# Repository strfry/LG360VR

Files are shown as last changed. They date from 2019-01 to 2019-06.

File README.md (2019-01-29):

# Summary

This about making the LG 360 VR Goggles usable with a normal DisplayPort outlet.

The LG360VR uses the "DisplayPort over USB-C" standard.
Our assumption is, that with little hardware effort, we can send a DisplayPort signal into it.

# Current State of things

- A passive PCB Adapter has been manufactured, though it doesn't work
- ~~Currently in the process of analyzing USB-PD communication, to figure out if this is the problem~~
  - Resolution: USB-PD Handshake is definitely necessary to get a display connection
- Now designing a new PCB with STM32F072 for PD Handshake and DisplayPort Redriver IC

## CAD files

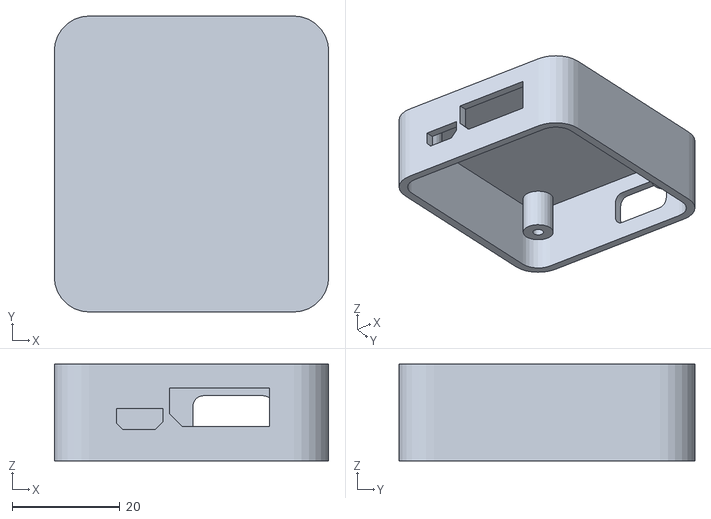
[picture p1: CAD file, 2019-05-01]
case/upper_case.stl
51.0 x 55.0 x 18.0

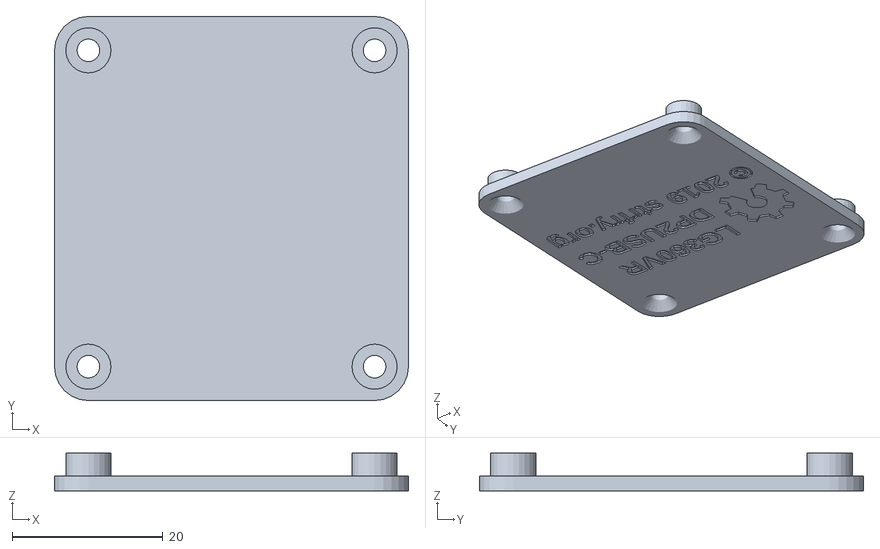
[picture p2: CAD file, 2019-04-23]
case/lower_lid_with_logo.stl
47.0 x 51.0 x 5.00

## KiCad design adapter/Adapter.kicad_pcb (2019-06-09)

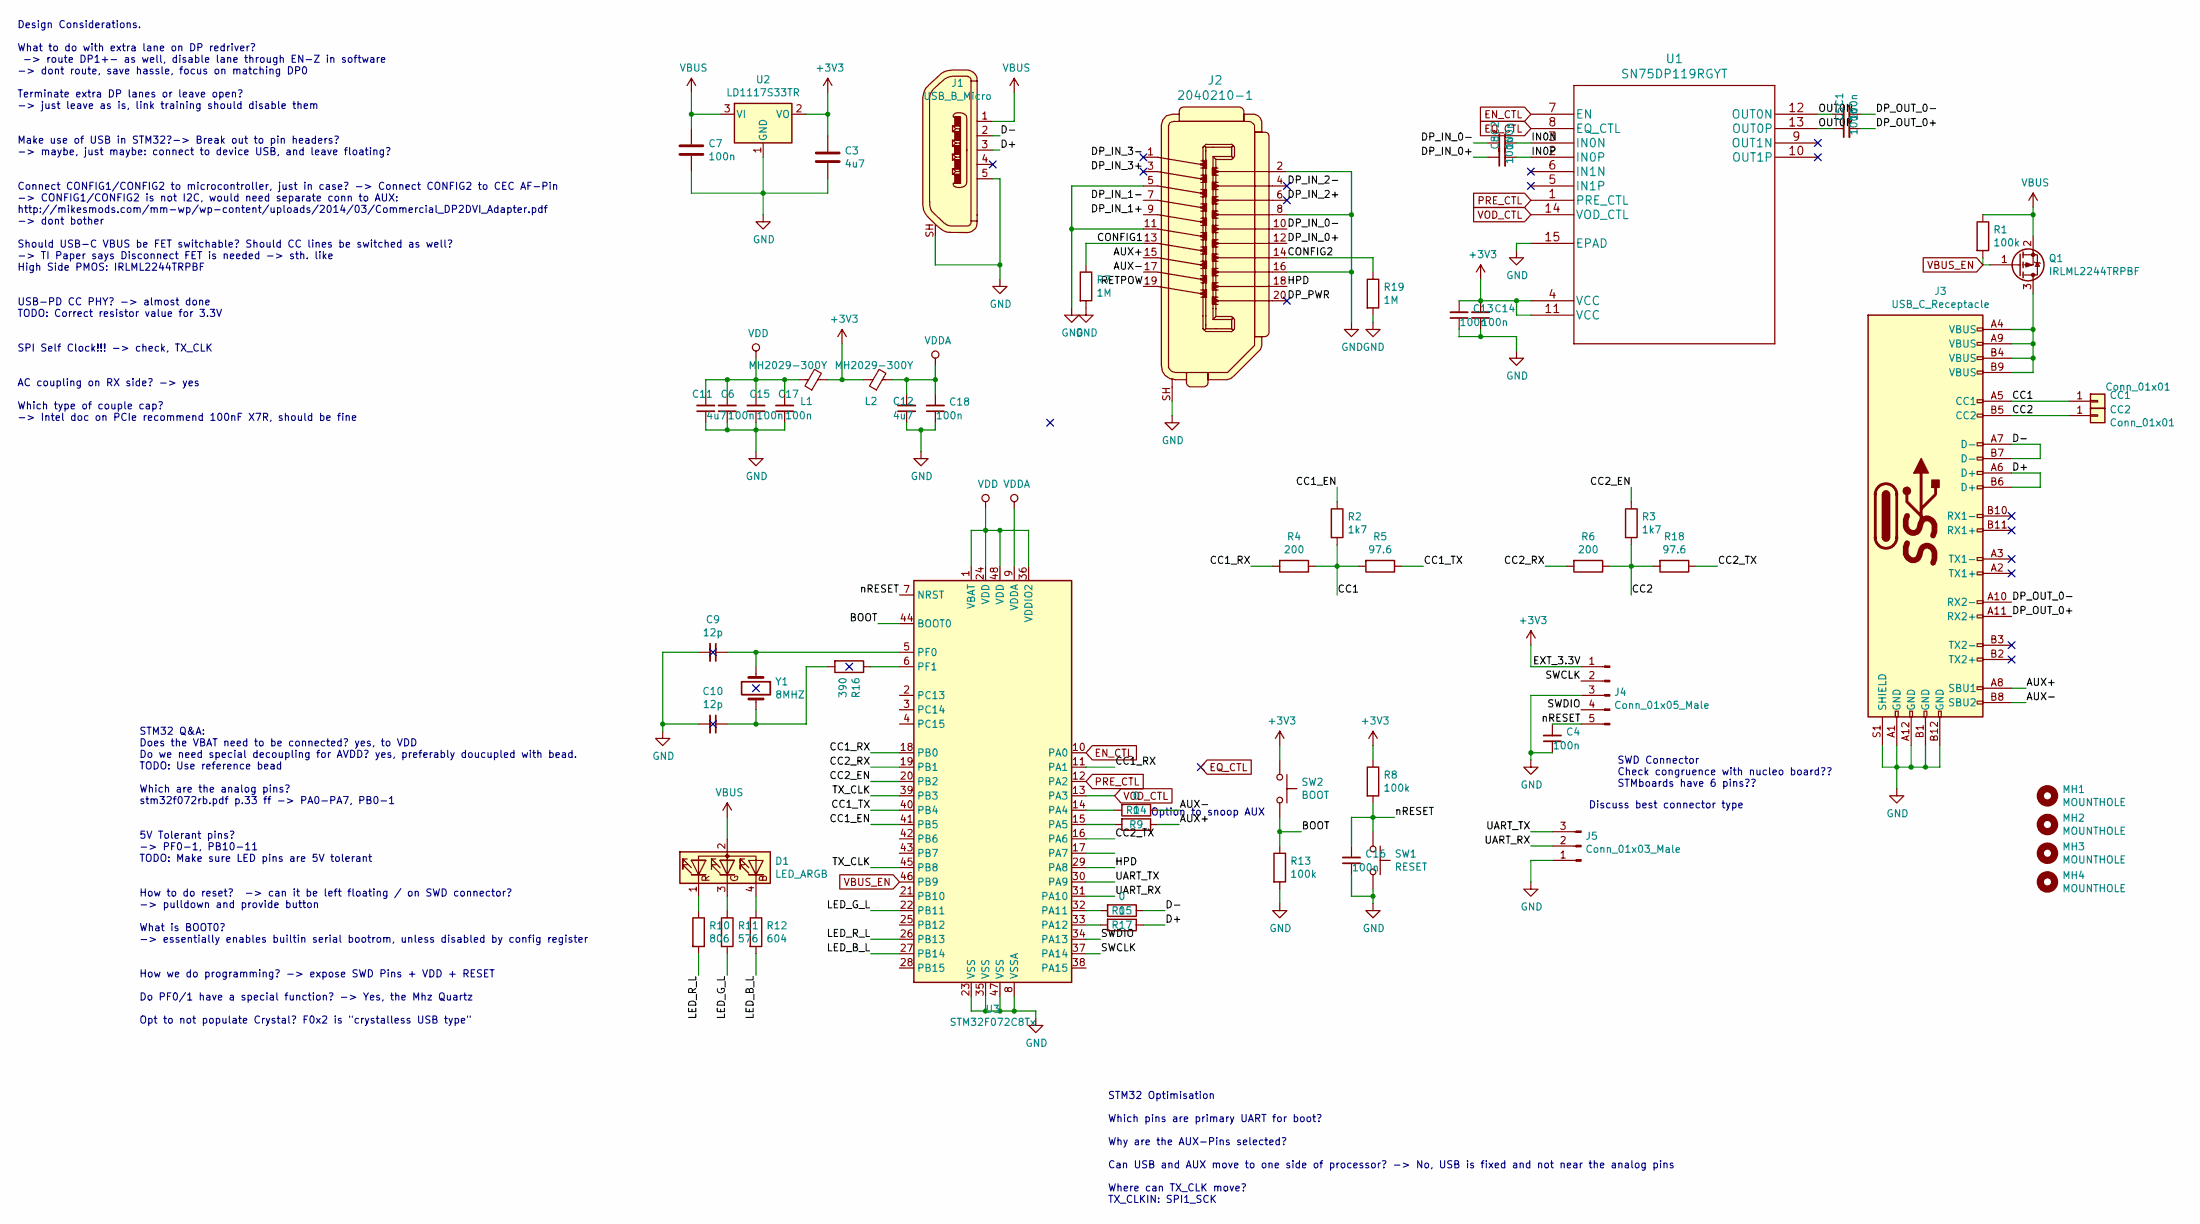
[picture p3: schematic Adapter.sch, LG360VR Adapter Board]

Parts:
C1, C2, C5, C8: 100n; C_0402_1005Metric
C3, C11, C12: 4u7; C_0603_1608Metric_Pad1.05x0.95mm_HandSolder
C4, C6, C7, C13, C14, C15, C16, C17, C18: 100n; C_0603_1608Metric_Pad1.05x0.95mm_HandSolder
C9, C10: 12p; C_0603_1608Metric_Pad1.05x0.95mm_HandSolder
CC1, CC2: Conn_01x01; TestPoint_Pad_D1.0mm
D1: LED_ARGB; LED_Cree-PLCC4_3.2x2.8mm_CCW
J1: USB_B_Micro; CONN-10118194-0001LF-FCI
J2: 2040210-1; DP1RD20JQ1R400
J3: USB_C_Receptacle; USB_C_Receptacle_Amphenol_12401610E4-2A
J4: Conn_01x05_Male; PinHeader_1x05_P2.54mm_Horizontal
J5: Conn_01x03_Male; PinHeader_1x03_P2.54mm_Horizontal
L1, L2: MH2029-300Y; L_0805_2012Metric_Pad1.15x1.40mm_HandSolder
MH1, MH2, MH3, MH4: MOUNTHOLE; MountingHole_2.5mm
Q1: IRLML2244TRPBF; SOT-23
R1, R8, R13: 100k; R_0603_1608Metric_Pad1.05x0.95mm_HandSolder
R2, R3: 1k7; R_0603_1608Metric_Pad1.05x0.95mm_HandSolder
R4, R6: 200; R_0603_1608Metric_Pad1.05x0.95mm_HandSolder
R5, R18: 97.6; R_0603_1608Metric_Pad1.05x0.95mm_HandSolder
R7, R19: 1M; R_0603_1608Metric_Pad1.05x0.95mm_HandSolder
R9, R14, R15, R17: 0; R_0603_1608Metric_Pad1.05x0.95mm_HandSolder
R10: 806; R_0603_1608Metric_Pad1.05x0.95mm_HandSolder
R11: 576; R_0603_1608Metric_Pad1.05x0.95mm_HandSolder
R12: 604; R_0603_1608Metric_Pad1.05x0.95mm_HandSolder
R16: 390; R_0603_1608Metric_Pad1.05x0.95mm_HandSolder
SW1: RESET; EVQPLMA15
SW2: BOOT; EVQPLMA15
U1: SN75DP119RGYT
U2: LD1117S33TR; SOT-223-3_TabPin2
U3: STM32F072C8Tx; LQFP-48_7x7mm_P0.5mm
Y1: 8MHZ; Crystal_SMD_TXC_7A-2Pin_5x3.2mm

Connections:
+3V3: C3.1, C13.2, C14.2, J4.1, L1.2, L2.1, R8.1, SW2.1, U1.4 (VCC), U1.11 (VCC), U2.2 (VO)
/AUX+: J2.15, J3.A8 (SBU1), R9.1
/AUX-: J2.17, J3.B8 (SBU2), R14.1
/BOOT: R13.1, SW2.2, U3.44 (BOOT0)
/CC1: CC1.1, J3.A5 (CC1), R2.2, R4.1, R5.2
/CC1_EN: R2.1, U3.41 (PB5)
/CC1_RX: R4.2, U3.11 (PA1), U3.18 (PB0)
/CC1_TX: R5.1, U3.40 (PB4)
/CC2: CC2.1, J3.B5 (CC2), R3.2, R6.1, R18.2
/CC2_EN: R3.1, U3.20 (PB2)
/CC2_RX: R6.2, U3.19 (PB1)
/CC2_TX: R18.1, U3.16 (PA6)
/CONFIG1: J2.13, R7.1
/CONFIG2: J2.14, R19.1
/D+: J1.3, J3.A6 (D+), J3.B6 (D+), R17.1
/D-: J1.2, J3.A7 (D-), J3.B7 (D-), R15.1
/DP_IN_0+: C8.1, J2.12
/DP_IN_0-: C2.1, J2.10
/DP_IN_1+: J2.9
/DP_IN_1-: J2.7
/DP_IN_2+: J2.6
/DP_IN_2-: J2.4
/DP_IN_3+: J2.3
/DP_IN_3-: J2.1
/DP_OUT_0+: C5.2, J3.A11 (RX2+)
/DP_OUT_0-: C1.2, J3.A10 (RX2-)
/DP_PWR: J2.20
/HPD: J2.18, U3.29 (PA8)
/IN0N: C2.2, U1.3 (IN0N)
/IN0P: C8.2, U1.2 (IN0P)
/LED_B_L: R12.2, U3.27 (PB14)
/LED_G_L: R11.2, U3.22 (PB11)
/LED_R_L: R10.2, U3.26 (PB13)
/OUT0N: C1.1, U1.12 (OUT0N)
/OUT0P: C5.1, U1.13 (OUT0P)
/RETPOW: J2.19
/SWCLK: J4.2, U3.37 (PA14)
/SWDIO: J4.4, U3.34 (PA13)
/TX_CLK: U3.39 (PB3), U3.45 (PB8)
/UART_RX: J5.2, U3.31 (PA10)
/UART_TX: J5.3, U3.30 (PA9)
/nRESET: C4.2, C16.2, J4.5, R8.2, SW1.1, U3.7 (NRST)
EN_CTL: U1.7 (EN), U3.10 (PA0)
EQ_CTL: U1.8 (EQ_CTL)
GND: C3.2, C4.1, C6.1, C7.2, C9.2, C10.2, C11.1, C12.1, C13.1, C14.1, C15.1, C16.1, C17.1, C18.1, J1.5, J1.SH, J2.2, J2.5, J2.8, J2.11, J2.16, J2.SH, J3.A1 (GND), J3.A12 (GND), J3.B1 (GND), J3.B12 (GND), J3.S1 (SHIELD), J4.3, J5.1, R7.2, R13.2, R19.2, SW1.2, U1.15 (EPAD), U2.1 (GND), U3.8 (VSSA), U3.23 (VSS), U3.35 (VSS), U3.47 (VSS)
unnamed: C9.1, U3.5 (PF0), Y1.1
unnamed: C10.1, R16.2, Y1.2
unnamed: D1.1 (RK), R10.1
unnamed: D1.3 (GK), R11.1
unnamed: D1.4 (BK), R12.1
unnamed: J3.A4 (VBUS), J3.A9 (VBUS), J3.B4 (VBUS), J3.B9 (VBUS), Q1.3 (D)
unnamed: R9.2, U3.15 (PA5)
unnamed: R14.2, U3.14 (PA4)
unnamed: R15.2, U3.32 (PA11)
unnamed: R16.1, U3.6 (PF1)
unnamed: R17.2, U3.33 (PA12)
PRE_CTL: U1.1 (PRE_CTL), U3.12 (PA2)
VBUS: C7.1, D1.2 (A), J1.1, Q1.2 (S), R1.1, U2.3 (VI)
VBUS_EN: Q1.1 (G), R1.2, U3.46 (PB9)
VDD: C6.2, C11.2, C15.2, C17.2, L1.1, U3.1 (VBAT), U3.24 (VDD), U3.36 (VDDIO2), U3.48 (VDD)
VDDA: C12.2, C18.2, L2.2, U3.9 (VDDA)
VOD_CTL: U1.14 (VOD_CTL), U3.13 (PA3)

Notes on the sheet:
STM32 Q&A: Does the VBAT need to be connected? yes, to VDD Do we need special decoupling for AVDD? yes, preferably doucupled with bead. TODO: Use reference bead Which are the analog pins? stm32f072rb.pdf p.33 ff -> PA0-PA7, PB0-1 5V Tolerant pins? -> PF0-1, PB10-11 TODO: Make sure LED pins are 5V t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
Design Considerations. What to do with extra lane on DP redriver? -> route DP1+- as well, disable lane through EN-Z in software -> dont route, save hassle, focus on matching DP0 Terminate extra DP lanes or leave open? -> just leave as is, link training should disable them Make use of USB in STM32?-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
SWD Connector Check congruence with nucleo board?? STMboards have 6 pins??
Discuss best connector type
Option to snoop AUX
STM32 Optimisation Which pins are primary UART for boot? Why are the AUX-Pins selected? Can USB and AUX move to one side of processor? -> No, USB is fixed and not near the analog pins Where can TX_CLK move? TX_CLKIN: SPI1_SCK

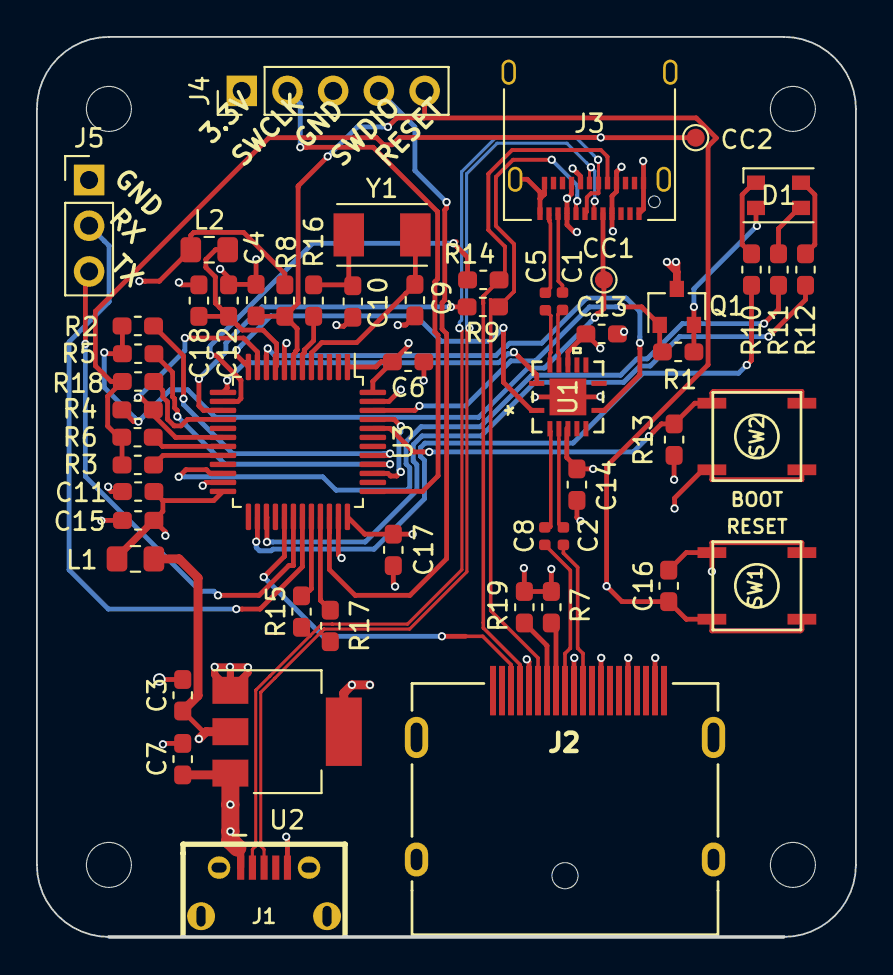
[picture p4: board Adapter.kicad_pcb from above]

Board: 4 copper layers, 45.5 x 50.0 mm, 58 parts (0 on the bottom side), 53 nets.

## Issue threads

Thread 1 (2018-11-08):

Where did you get displayport to usb-c pinout ?

RomSand, 2018-11-08:

strfry, 2018-11-09:
I'm not sure where i originally got it when designing the PCB, but there's a rather definitive description in this datasheet on page 17:
http://www.ti.com/lit/ds/sllsem7d/sllsem7d.pdf

Beware that the DisplayPort connector Pinout itself changes depending if it's a source or sink side! (DP Cable switches lane orientation)

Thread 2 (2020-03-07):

Has it worked till now?

RayforLoy, 2020-03-07:
I got a lgr100 from my friend and found youer project online. I'd like to make an adatper to get it work on my laptop, but I saw you posted as ' doesn't work'.

strfry, 2020-03-09:
It does work. Only problem being, there is no software specifically made for the LG-R100.
You're on your own to write a driver or app based on OpenHMD, but is has to deal with the weird display orientation, that isn't common among others VR systems.

beckmx, 2024-03-31:
hello @strfry if i understand the repo, this is a usbc to display port, correct?, I also noticed another repository https://github.com/bauermaximilian/LG-360-VR-for-PC, that should make the transition correctly, and last question, do you still have a prototype to sell?

Closed 2020-03-09.

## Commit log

2018-07-08 initial version (with most likely wrong lane ordering)
    [Adapter.kicad_pcb, Adapter.sch]
2018-07-09 Reverse DP Lanes, connect Shield to GND
    [Adapter.sch]
2018-07-09 New design with DP and USB-mB on same side
    [Adapter.kicad_pcb]
2018-07-21 4-Layer-Design with correct DP Lane polarity and impedance matching
    [Adapter.kicad_pcb, Adapter.sch]
2018-07-21 cosmetic changes
    [Adapter.kicad_pcb]
2018-07-22 Re-matched and DRCed for OSHPark's 4 Layer Process
    [Adapter.kicad_pcb]
2018-10-21 Move PCB stuff into hardware/ directory
    [Adapter-B.Cu.gbr, Adapter-B.Mask.gbr, Adapter-B.Paste.gbr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]
2018-10-21 rename hardware to adapter, add USB-C footprint
    [Adapter-B.Cu.gbr, Adapter-B.Mask.gbr, Adapter-B.Paste.gbr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]
2019-01-28 created new footprint and symbols for DP redriver IC
2019-01-29 Design considerations and fixed most external circuitry for STM32
    [Adapter.kicad_pcb, Adapter.sch]
2019-02-01 cleared a bunch of questions
    [Adapter.kicad_pcb, Adapter.sch]
2019-02-01 used most of stm32 pinning from twinkie board
    [Adapter.sch]
2019-02-03 pre-place most of components
    [Adapter.kicad_pcb, Adapter.sch]
2019-02-03 Added 3D STEP for micro-USB Jack
    [Adapter.kicad_pcb, Adapter.sch]
2019-02-03 Compatible Molex DisplayPort connector 3d file
2019-02-03 Step file for MicroUSB
    [Adapter.kicad_pcb, Adapter.sch]
2019-02-03 sync changs from tmp checkout
    [Adapter.kicad_pcb, Adapter.sch]
2019-02-03 renamed custom footprints
    [Adapter.kicad_pcb, Adapter.sch]
2019-02-04 more 3d packages...
    [Adapter.kicad_pcb, Adapter.sch]
2019-02-04 remove the bead for the DP119
    [Adapter.kicad_pcb, Adapter.sch]
2019-02-04 Added 2 missing STEP files
    [Adapter.kicad_pcb, Adapter.sch]
2019-02-06 state published at http://strfry.org/lg360vr-schematic.pdf
    [Adapter.sch]
2019-02-08 Replaced SN75DP119 symbol/footprint with premade one from Arrow librarian
    [Adapter.kicad_pcb, Adapter.sch]
2019-02-08 cleared all order number for Arrow
    [Adapter.kicad_pcb, Adapter.sch]
2019-02-13 placement mostly done
    [Adapter.kicad_pcb, Adapter.sch]
2019-02-14 first fully routed
    [Adapter.kicad_pcb, Adapter.sch]
2019-02-16 shifting back some components from the USB-C jack
    [Adapter.kicad_pcb, Adapter.sch]
2019-02-20 Connect EXT3.3V to 3.3V
    [Adapter.kicad_pcb, Adapter.sch]
2019-02-20 squashed out a mm to stay within 50x50 mm discount
    [Adapter-B.Cu.gbr, Adapter-B.Mask.gbr, Adapter-B.Paste.gbr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]
2019-02-20 retraced impedance critical paths
    [Adapter.kicad_pcb, Adapter.sch]
2019-02-20 corrected USB impedance
    [Adapter-B.Cu.gbr, Adapter-B.Mask.gbr, Adapter-B.Paste.gbr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]
2019-02-20 remove silkscreen from pin header footprints
    [Adapter-B.Cu.gbr, Adapter-B.Mask.gbr, Adapter-B.Paste.gbr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]
2019-02-20 no silkscreen at bottom
    [Adapter-B.Cu.gbr, Adapter-B.Mask.gbr, Adapter-B.Paste.gbr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]
2019-03-31 simple enclosure
2019-04-02 logo and optimized holes
2019-04-23 add stl exports
    [lower_lid_with_logo.stl, upper_case.stl]
2019-05-01 correctly re-exported upper_case (with USB-C hole)
    [upper_case.stl]
2019-06-09 fix distance between DP and µUSB connector
    [Adapter.kicad_pcb]
2019-06-09 fix the PA1 connection (the cheap way, as in prototype)
    [Adapter.kicad_pcb, Adapter.sch]
2019-06-09 enter unpopulated parts note
    [Adapter.kicad_pcb, Adapter.sch]

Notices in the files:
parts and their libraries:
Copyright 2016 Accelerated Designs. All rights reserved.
